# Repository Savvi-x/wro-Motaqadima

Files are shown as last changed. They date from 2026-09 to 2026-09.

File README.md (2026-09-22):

# WRO 2026 Future Engineers
## Autonomous Vehicle Project – Team 6001

<p align="center">
  <b>World Robot Olympiad 2026 – Future Engineers</b><br>
  Autonomous Driving Vehicle
</p>

---

## Team Information

**Team Name:** المتقدمة2  
**Team Number:** 6001  

### Team Members
- Faisal Abdullah Faisal Al-Rashidan
- Eyad Waleed Omar Khdejoos

# 1. Project Overview

This repository documents the design, development, programming, testing, and improvement process of our autonomous vehicle for the **WRO 2026 Future Engineers** category.

The goal of the project is to develop a fully autonomous four-wheel vehicle capable of navigating the WRO Future Engineers track without external control.

The vehicle is designed to complete two main competition challenges:

1. **Open Challenge**
2. **Obstacle Challenge**

For the Open Challenge, the vehicle must autonomously navigate the track and complete three laps while adapting to the track configuration.

For the Obstacle Challenge, the vehicle must recognize red and green traffic pillars, choose the correct driving side, complete three laps, and finally perform the parking task.

Our design focuses on:

- Reliable autonomous navigation
- Computer vision
- Distance measurement
- Sensor fusion
- Accurate steering
- Stable vehicle control
- Modular software
- Fast sensor processing
- Repeatable testing and calibration

---

# 2. Vehicle Architecture

The vehicle uses a distributed control architecture.

The main processing tasks are divided between:

### Raspberry Pi 5

The Raspberry Pi 5 is the high-level controller of the vehicle.

Its main responsibilities include:

- Camera processing
- Computer vision
- Traffic pillar detection
- Navigation decisions
- Challenge logic
- State machine control
- Sensor data processing
- Communication with the low-level controller

### Raspberry Pi Pico W

The Raspberry Pi Pico W is used as the low-level real-time controller.

Its responsibilities include:

- Steering servo control
- DC motor control
- Distance sensor reading
- Fast actuator commands
- Communication with the Raspberry Pi 5

Although the Pico W contains wireless hardware, wireless communication is not used during competition operation.

Communication between the Raspberry Pi and the vehicle electronics is implemented using wired communication.

---

# 3. System Block Diagram

The general architecture of the robot is:

```text
                     +----------------------+
                     |    Raspberry Pi 5    |
                     |                      |
Camera Module ------>| Computer Vision      |
                     | Navigation           |
                     | State Machine        |
                     | Decision Making      |
                     +----------+-----------+
                                |
                           USB / UART
                                |
                     +----------v-----------+
                     | Raspberry Pi Pico W  |
                     |                      |
                     | Motor Control        |
                     | Steering Control     |
                     | Sensor Interface     |
                     +----+----------+------+
                          |          |
                       Servo      Motor Driver
                          |          |
                     Steering     DC Motor
                          |
                 Distance Sensors / IMU

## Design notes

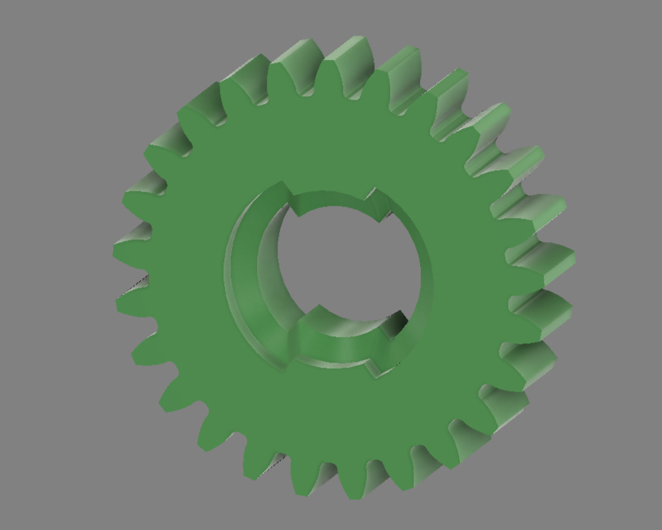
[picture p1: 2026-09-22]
models/CAD_design_spur_25_gear_1.jpg

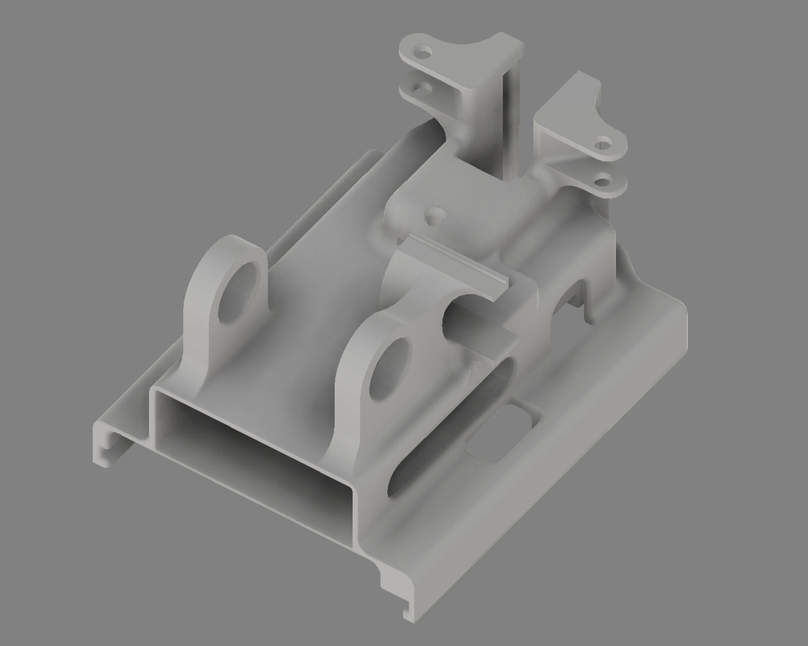
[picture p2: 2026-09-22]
models/CAD_design_base_2.jpg

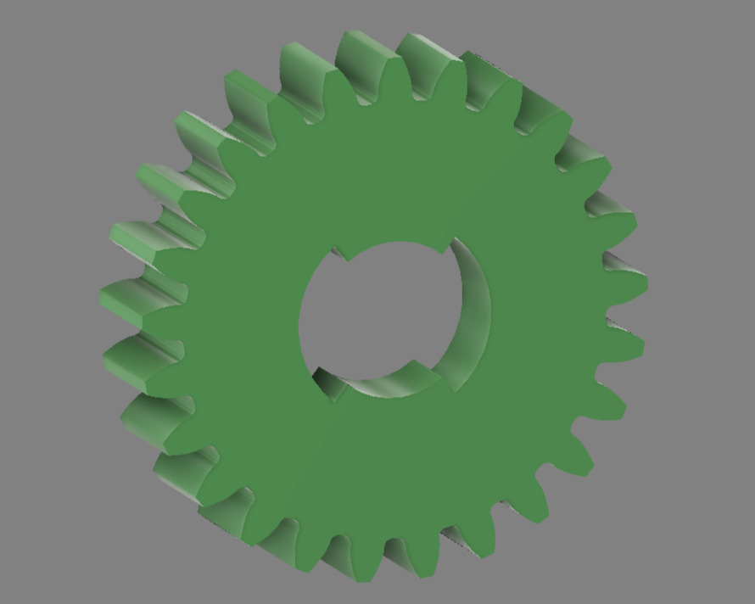
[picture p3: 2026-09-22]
models/CAD_design_spur_25_gear_2.jpg

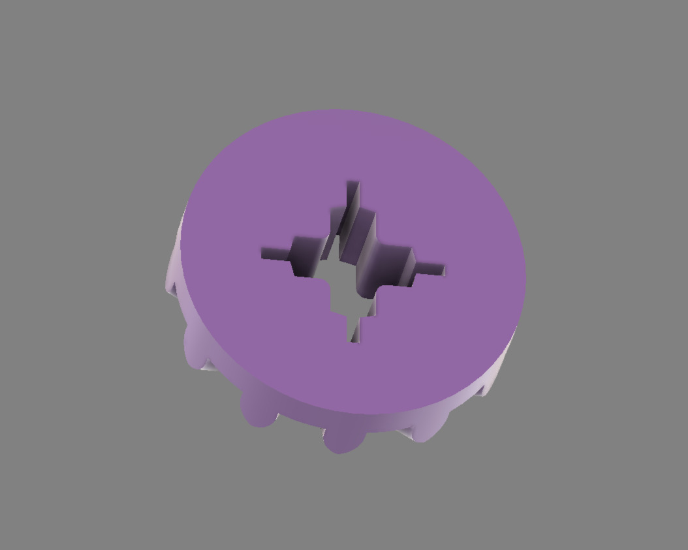
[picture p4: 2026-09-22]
models/CAD_design_bevel_12_gear_2.jpg

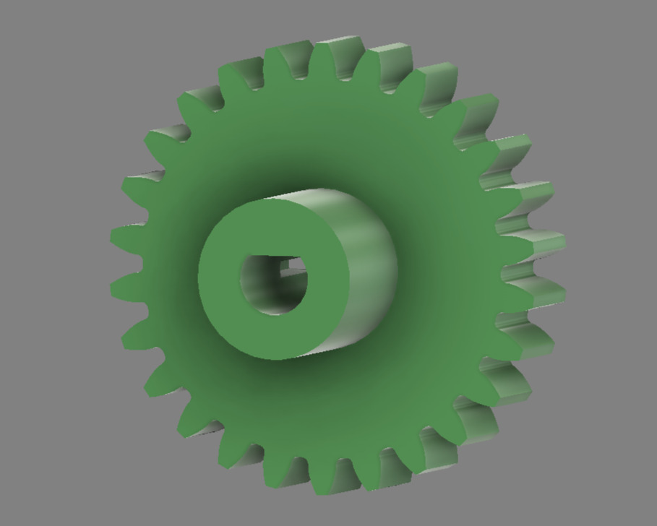
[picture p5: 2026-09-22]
models/CAD_design_spur_26_gear_2.jpg

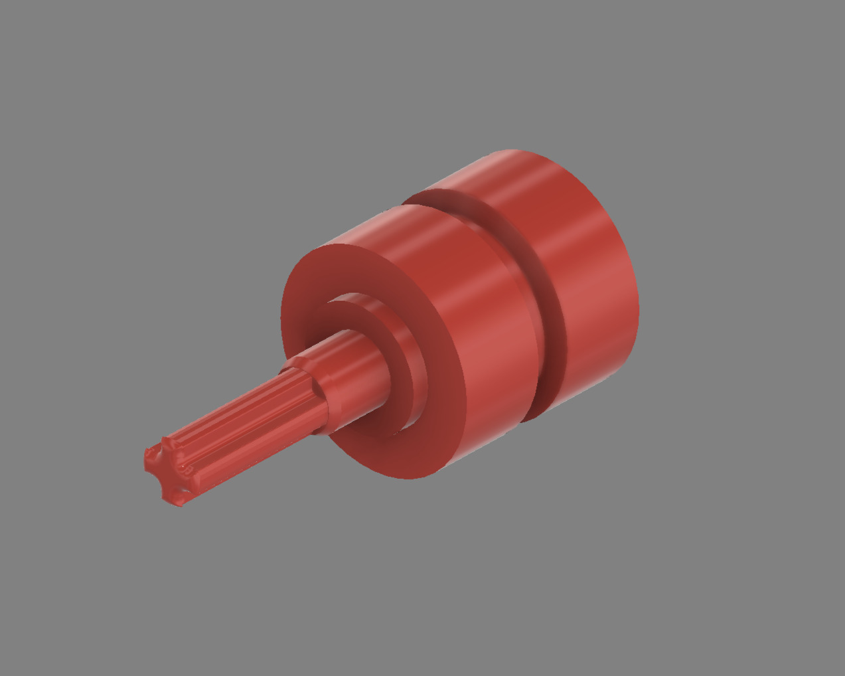
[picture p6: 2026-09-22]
models/CAD_design_back_rim_long.jpg

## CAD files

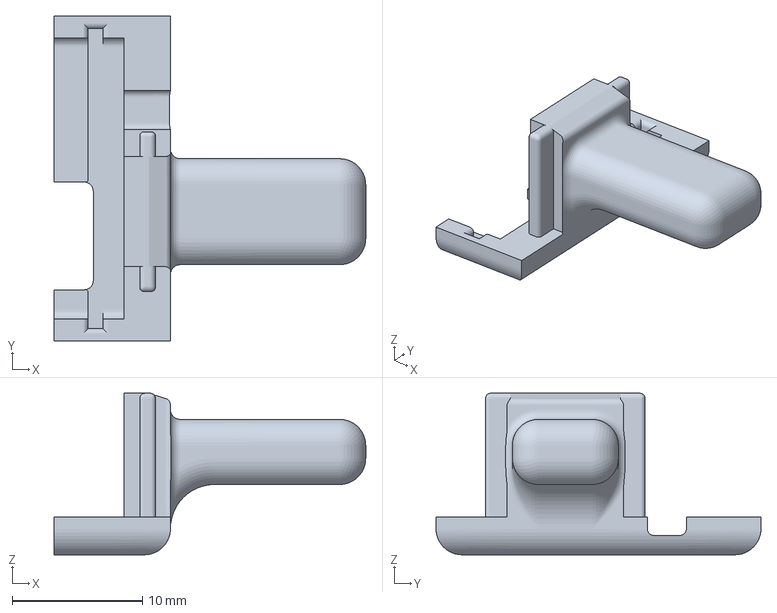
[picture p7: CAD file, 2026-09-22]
models/design_front_top_cover.3mf
23.9 x 25.0 x 12.4 mm

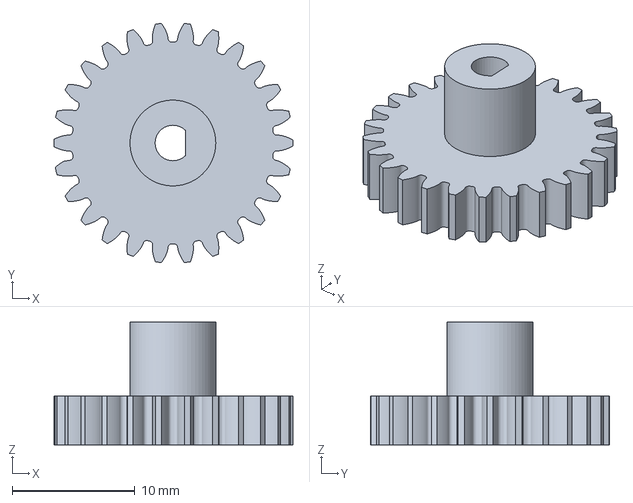
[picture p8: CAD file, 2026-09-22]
models/design_spur_26_gear.3mf
19.5 x 19.5 x 10.0 mm

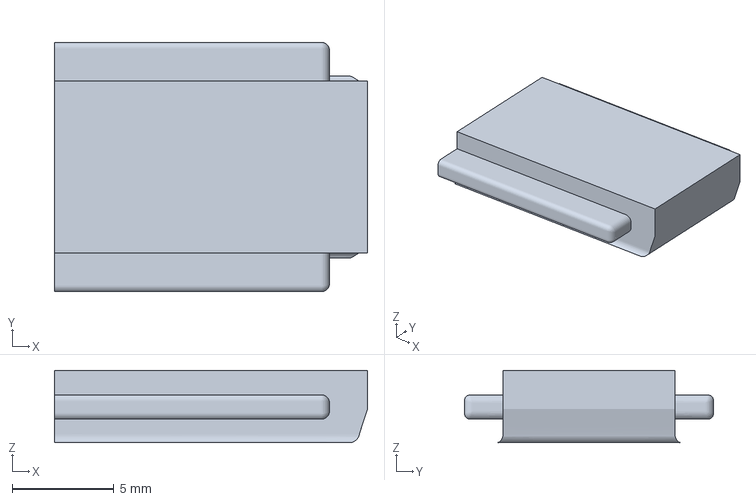
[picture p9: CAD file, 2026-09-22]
models/design_front_bottom_cover.3mf
15.4 x 12.3 x 3.56 mm

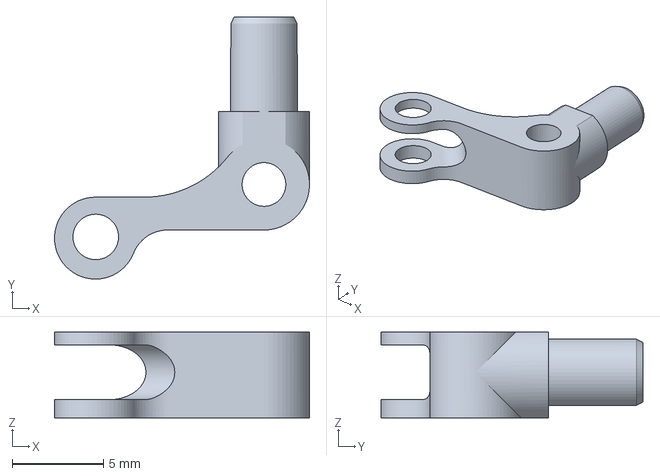
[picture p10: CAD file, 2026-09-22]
models/design_steering_arm.3mf
14.0 x 14.4 x 4.70 mm

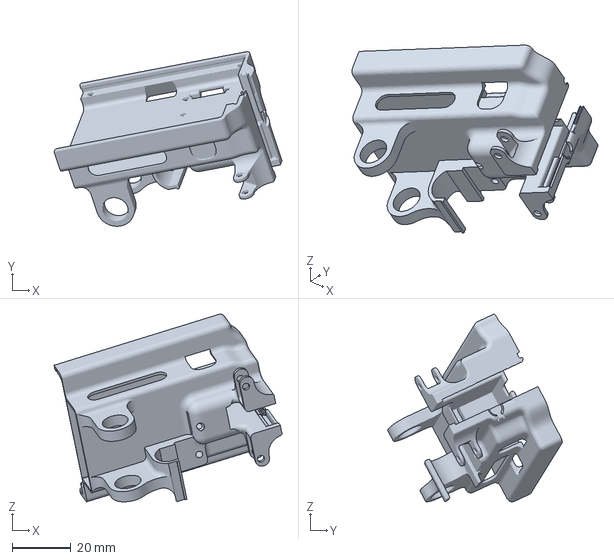
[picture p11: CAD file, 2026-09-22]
models/design_base.3mf
77.3 x 59.2 x 63.7 mm

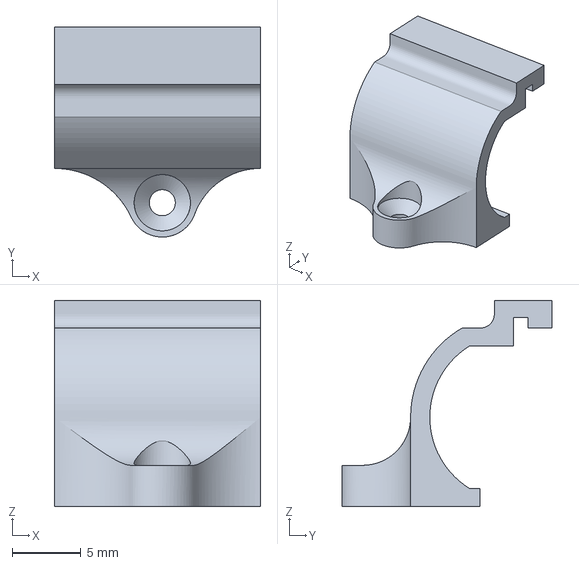
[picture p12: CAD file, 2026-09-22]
models/design_motor_lid.3mf
15.0 x 15.3 x 15.0 mm

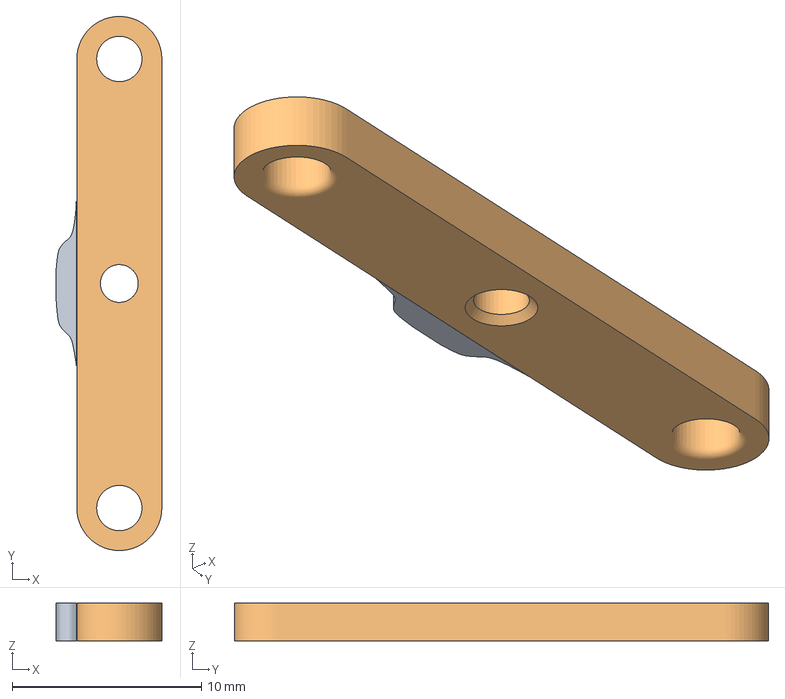
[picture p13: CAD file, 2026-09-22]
models/design_steering_linkage.3mf
5.59 x 28.3 x 2.00 mm
STEERING_LINKAGE (1)
STEERING_LINKAGE

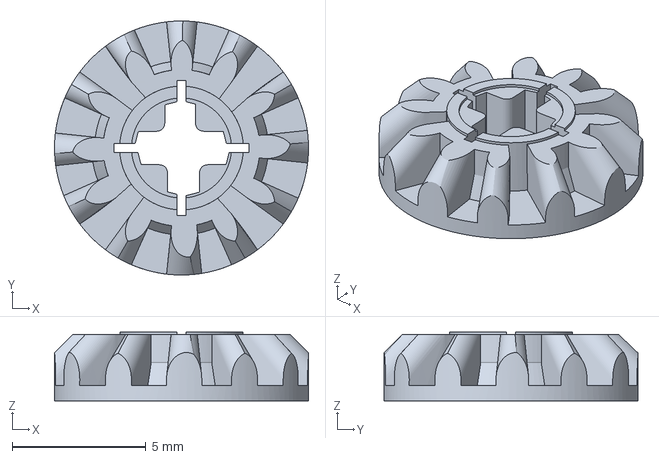
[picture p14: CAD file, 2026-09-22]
models/design_bevel_12_gear.3mf
9.49 x 9.49 x 2.58 mm

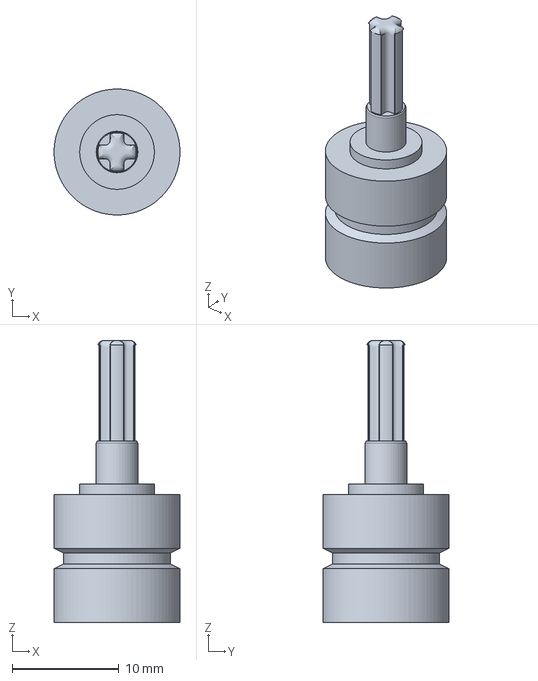
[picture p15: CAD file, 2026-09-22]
models/design_back_rim_long.3mf
11.8 x 11.8 x 26.4 mm

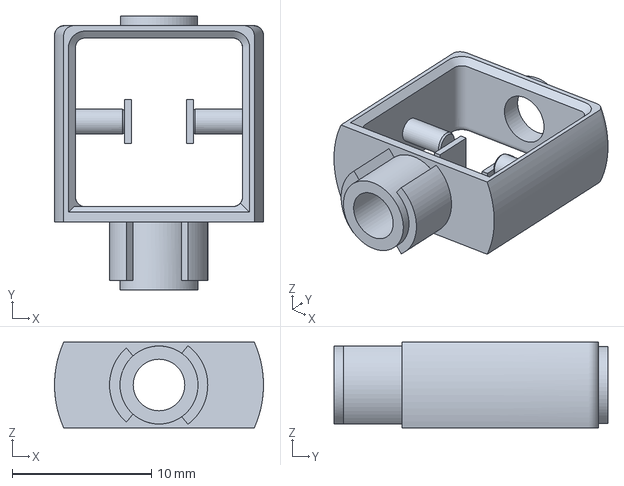
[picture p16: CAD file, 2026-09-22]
models/design_4_gear_mini_differential.3mf
15.0 x 19.6 x 6.15 mm

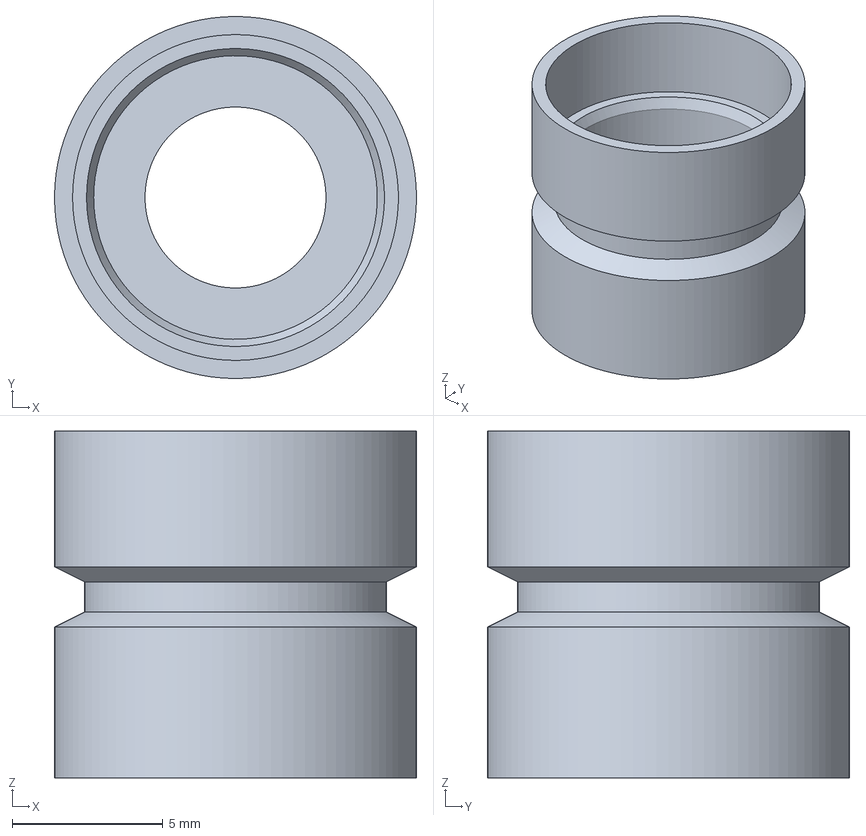
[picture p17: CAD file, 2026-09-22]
models/design_front_rim_bearing.3mf
12.0 x 12.0 x 11.5 mm

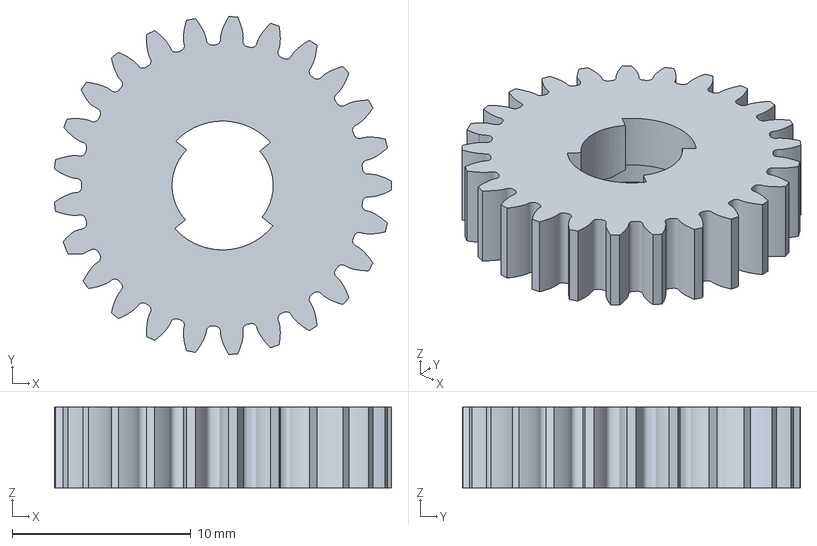
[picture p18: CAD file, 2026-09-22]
models/design_spur_25_gear.3mf
18.9 x 18.9 x 4.50 mm

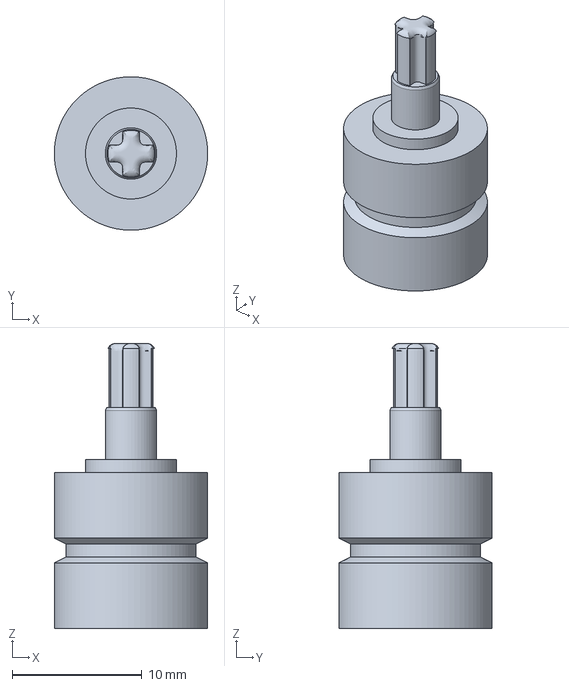
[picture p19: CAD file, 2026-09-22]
models/design_back_rim_short.3mf
11.8 x 11.8 x 21.9 mm

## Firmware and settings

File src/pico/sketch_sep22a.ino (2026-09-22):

#include <Servo.h>

// =====================================================
// WRO 2026 FUTURE ENGINEERS
// TEAM 6001
// LOW LEVEL CONTROLLER
// Raspberry Pi Pico W
// =====================================================


// =====================================================
// SERVO
// =====================================================

#define SERVO_PIN 15

#define STEER_LEFT     20
#define STEER_CENTER   83
#define STEER_RIGHT   145

Servo steering;


// =====================================================
// L293D MOTOR DRIVER
// =====================================================

#define MOTOR_IN1 16
#define MOTOR_IN2 17
#define MOTOR_EN  18


// =====================================================
// MOTOR SPEED
// =====================================================

int motorSpeed = 255;


// =====================================================
// FAILSAFE
// =====================================================

unsigned long lastCommandTime = 0;

const unsigned long COMMAND_TIMEOUT = 500;


// =====================================================
// MOTOR FORWARD
// =====================================================

void motorForward()
{
  // Direction corrected after physical testing

  digitalWrite(MOTOR_IN1, LOW);
  digitalWrite(MOTOR_IN2, HIGH);

  analogWrite(MOTOR_EN, motorSpeed);
}


// =====================================================
// MOTOR BACKWARD
// =====================================================

void motorBackward()
{
  digitalWrite(MOTOR_IN1, HIGH);
  digitalWrite(MOTOR_IN2, LOW);

  analogWrite(MOTOR_EN, motorSpeed);
}


// =====================================================
// MOTOR STOP
// =====================================================

void motorStop()
{
  analogWrite(MOTOR_EN, 0);

  digitalWrite(MOTOR_IN1, LOW);
  digitalWrite(MOTOR_IN2, LOW);
}


// =====================================================
// COMMAND PROCESSOR
// =====================================================

void processCommand(char cmd)
{
  lastCommandTime = millis();

  switch (cmd)
  {

    // ---------------------------------
    // Forward
    // ---------------------------------

    case 'F':

      motorForward();

      break;


    // ---------------------------------
    // Backward
    // ---------------------------------

    case 'B':

      motorBackward();

      break;


    // ---------------------------------
    // Stop
    // ---------------------------------

    case 'S':

      motorStop();

      break;


    // ---------------------------------
    // Steering Left
    // ---------------------------------

    case 'L':

      steering.write(STEER_LEFT);

      break;


    // ---------------------------------
    // Steering Right
    // ---------------------------------

    case 'R':

      steering.write(STEER_RIGHT);

      break;


    // ---------------------------------
    // Steering Center
    // ---------------------------------

    case 'C':

      steering.write(STEER_CENTER);

      break;
  }
}


// =====================================================
// SETUP
// =====================================================

void setup()
{

  // USB communication with Raspberry Pi

  Serial.begin(115200);


  // Motor pins

  pinMode(MOTOR_IN1, OUTPUT);
  pinMode(MOTOR_IN2, OUTPUT);
  pinMode(MOTOR_EN, OUTPUT);


  // Stop motor at startup

  motorStop();


  // Steering

  steering.attach(SERVO_PIN);

  steering.write(STEER_CENTER);


  delay(1000);


  lastCommandTime = millis();
}


// =====================================================
// LOOP
// =====================================================

void loop()
{

  // ==========================================
  // RECEIVE COMMAND FROM RASPBERRY PI
  // ==========================================

  while (Serial.available())
  {

    char command = Serial.read();

    processCommand(command);

  }


  // ==========================================
  // FAILSAFE
  // ==========================================

  if (millis() - lastCommandTime > COMMAND_TIMEOUT)
  {

    motorStop();

  }
}

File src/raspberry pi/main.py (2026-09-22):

import cv2
import time

from uart import PicoUART
from vision import VisionSystem
from navigation import Navigator


# ==========================================
# SETTINGS
# ==========================================

SHOW_CAMERA = True

LOOP_DELAY = 0.03


# ==========================================
# INITIALIZE
# ==========================================

print("--------------------------------")
print("WRO 2026 FUTURE ENGINEERS")
print("TEAM 6001")
print("--------------------------------")


pico = PicoUART(
    port="/dev/ttyACM0",
    baudrate=115200
)

if not pico.connect():

    print("Pico connection failed.")
    exit()


vision = VisionSystem()

navigator = Navigator()


# ==========================================
# START STATE
# ==========================================

pico.stop()
pico.center()

time.sleep(2)

print("[SYSTEM] Robot ready")


# ==========================================
# MAIN LOOP
# ==========================================

try:

    while True:

        # --------------------------
        # Camera processing
        # --------------------------

        vision_result = vision.process()

        # --------------------------
        # Navigation decision
        # --------------------------

        command = navigator.calculate(
            vision_result
        )

        drive = command["drive"]
        steering = command["steering"]
        state = command["state"]

        # --------------------------
        # Motor command
        # --------------------------

        if drive == "F":

            pico.forward()

        elif drive == "B":

            pico.backward()

        else:

            pico.stop()

        # --------------------------
        # Steering command
        # --------------------------

        if steering == "L":

            pico.left()

        elif steering == "R":

            pico.right()

        else:

            pico.center()

        # --------------------------
        # Debug
        # --------------------------

        print(
            f"STATE: {state:15} "
            f"DRIVE: {drive} "
            f"STEERING: {steering}"
        )

        # --------------------------
        # Camera window
        # --------------------------

        if SHOW_CAMERA:

            display = vision.draw_detection(
                vision_result
            )

            cv2.putText(
                display,
                f"STATE: {state}",
                (20, 40),
                cv2.FONT_HERSHEY_SIMPLEX,
                1,
                (255, 255, 255),
                2
            )

            cv2.imshow(
                "WRO 2026 - Team 6001",
                display
            )

            key = cv2.waitKey(1)

            if key == ord("q"):
                break

        time.sleep(LOOP_DELAY)


# ==========================================
# SAFE SHUTDOWN
# ==========================================

except KeyboardInterrupt:

    print("\n[SYSTEM] CTRL+C")


finally:

    print("[SYSTEM] STOPPING")

    pico.stop()
    pico.center()

    vision.close()
    pico.close()

    print("[SYSTEM] OFF")
